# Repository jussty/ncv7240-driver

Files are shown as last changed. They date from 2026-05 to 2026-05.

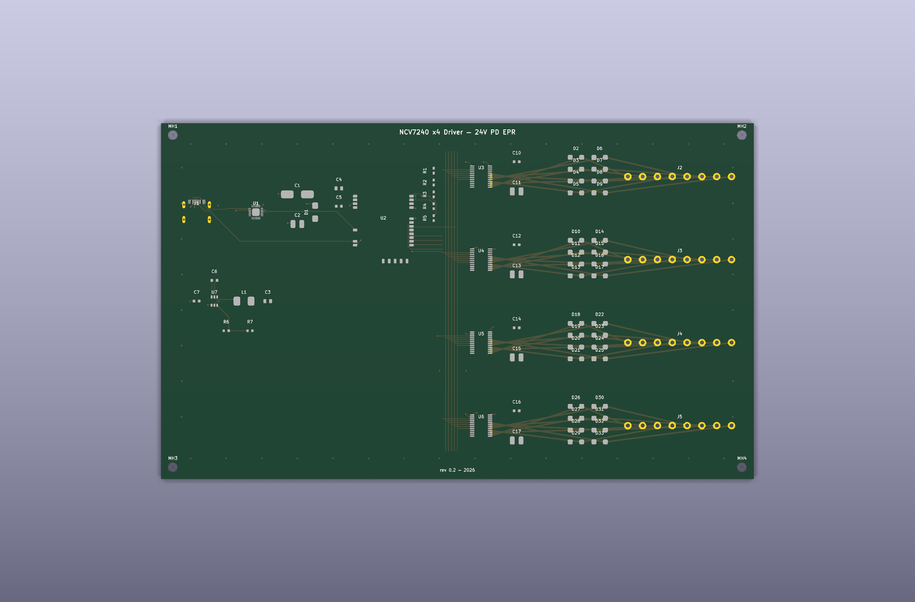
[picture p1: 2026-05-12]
board-top-routed.png

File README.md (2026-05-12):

# NCV7240 x4 — ESP32 + USB-C PD EPR (24 V) Driver Board

A KiCad 8 project for a compact controller board that:

- Negotiates **24 V** from a USB-C **PD 3.1 EPR** source via the **AP33772S** sink controller.
- Hosts an **ESP32-S3** MCU for Wi-Fi/BT control, configuration and host comms.
- Drives **32 low-side switched outputs** at 24 V using **4 × NCV7240** octal low-side drivers (SPI-controlled).

> Status: skeleton — project files, design rules, net classes and BOM are in place. The schematic (`ncv7240-driver.kicad_sch`) and PCB (`ncv7240-driver.kicad_pcb`) are intentionally empty placeholders ready to be populated in KiCad 8.

---

## 1. System architecture

```
       USB-C (PD 3.1 EPR, up to 28 V / 5 A)
           │
           ▼
   ┌────────────────┐   I²C   ┌──────────────────────┐
   │   AP33772S     │◀───────▶│   ESP32-S3-WROOM-1   │
   │  PD EPR sink   │  (CFG)  │  (Wi-Fi / BT / USB)  │
   └──────┬─────────┘         └───────┬──────────────┘
          │ VBUS_OUT = 24 V           │ SPI (CS x4, SCK, MOSI, MISO)
          │                           │ + RSTB, /FSO IRQ
          ▼                           ▼
   ┌──────────────┐   ┌──────────────┐   ┌──────────────┐   ┌──────────────┐
   │  NCV7240 #1  │   │  NCV7240 #2  │   │  NCV7240 #3  │   │  NCV7240 #4  │
   │ 8 ch low-side│   │ 8 ch low-side│   │ 8 ch low-side│   │ 8 ch low-side│
   └──────┬───────┘   └──────┬───────┘   └──────┬───────┘   └──────┬───────┘
          ▼                  ▼                  ▼                  ▼
       OUT1..8            OUT9..16          OUT17..24          OUT25..32
       (loads sink to GND; common rail = 24 V)
```

- The AP33772S handles all CC negotiation/PPS/EPR; the ESP32 just configures the
  request profile over I²C and reads VBUS / status telemetry.
- The 4 NCV7240s share SCK/MOSI/MISO/RSTB/SI on a single SPI bus; each has its
  own **/CSB** from the ESP32. Output enable is per-channel via SPI control word.

## 2. Bill of materials (core)

| Ref | Part | Pkg | Notes |
|---|---|---|---|
| U1 | AP33772S | QFN-24 | USB-C PD 3.1 EPR sink controller |
| U2 | ESP32-S3-WROOM-1-N8R8 | SMD module | 8 MB flash, 8 MB PSRAM |
| U3..U6 | NCV7240ADQR2G | SSOP-24 | Octal low-side driver, SPI |
| J1 | USB-C receptacle (EPR rated)  | TID/16-pin | 5 A continuous, EPR cable required >3 A  |
| D1 | TVS for VBUS (e.g. SMBJ33A) | SMB | 33 V standoff |
| L1 | 10 µH @ 3 A ferrite/inductor  | 1210 | VBUS LC filter (optional) |
| C_BULK | 100 µF / 50 V × 2 | electrolytic | VBUS bulk on 24 V rail |
| FB1..FB4  | Ferrite bead, 600 Ω @ 100 MHz | 0603 | Per-NCV7240 V_PWR decoupling |
| U7 | LDO/buck 24 V → 3.3 V (e.g. MP2451 or TPS62932) | SOT-23-6 | ≥500 mA for ESP32 peaks |
| U8 | (optional) 3.3 V LDO | SOT-23-5 | Clean rail for analog if needed |
| Q_GATE | P-MOSFET (e.g. DMP3098L) | SOT-23 | Reverse-polarity / VBUS gate (optional)  |
| R_CS | 1 % shunts | 0805 | If per-bank current sensing is desired |

Plus per-channel flyback diodes/TVS if driving inductive loads (the NCV7240
has internal active clamp, but external TVS to 24 V rail is recommended for
solenoids/relays).

## 3. Net classes / design rules

Defined in `ncv7240-driver.kicad_pro`:

| Net class | Track | Clearance | Vias | Used for |
|---|---|---|---|---|
| Default | 0.25  | 0.20 | 0.6 / 0.3 | logic, SPI, I²C |
| Power_24V | 0.80  | 0.40 | 0.9 / 0.4 | VBUS, 24 V plane feeds, OUTx pours |
| USB_PD | 0.40  | 0.25 | 0.7 / 0.3 | CC1/CC2, VBUS sense, D+/D- (90 Ω diff)|

## 4. Pin assignment (ESP32-S3 → NCVs / AP33772S)

| ESP32 pin | Net | Goes to |
|---|---|---|
| GPIO10 | SPI_CS1 | NCV7240 #1 /CSB |
| GPIO11 | SPI_CS2 | NCV7240 #2 /CSB |
| GPIO12 | SPI_CS3 | NCV7240 #3 /CSB |
| GPIO13 | SPI_CS4 | NCV7240 #4 /CSB |
| GPIO14 | SPI_SCK | all NCV7240 SCLK |
| GPIO15 | SPI_MOSI | all NCV7240 SI |
| GPIO16 | SPI_MISO | all NCV7240 SO (open-drain, ext. pull-up)|
| GPIO17 | NCV_RSTB | all NCV7240 /RSTB (active low, pull-up)  |
| GPIO18 | NCV_FSO | all NCV7240 /FSO fault flag (IRQ) |
| GPIO8 | I2C_SDA | AP33772S SDA (+ 4.7 kΩ pull-up to 3V3) |
| GPIO9 | I2C_SCL | AP33772S SCL (+ 4.7 kΩ pull-up to 3V3) |
| GPIO4 | PD_INT | AP33772S /INT |
| EN | reset btn | per ESP32 standard wiring |
| GPIO0 | boot btn | per ESP32 standard wiring |

> Avoid the strapping pins (GPIO0/3/45/46) and USB pins (19/20) for the
> dedicated nets above — already accounted for.

## 5. NCV7240 wiring notes

- Tie all `V_PWR` pins to the 24 V rail through individual ferrite beads
  + 100 nF + 10 µF local decoupling per IC.
- All `GND` pins tied to the solid 24 V-return ground pour.
- `SO` is open-drain; place one 10 kΩ pull-up to 3V3 on the shared MISO net.
- `/RSTB` shared and pulled up to 3V3 (10 kΩ); ESP32 drives low to reset all.
- `/FSO` shared open-drain fault flag → ESP32 IRQ, pulled up to 3V3.
- Daisy-chained SPI is **not** used here (independent /CSB per device is
  simpler and lets the ESP32 talk to any device individually at full clock).
- Each OUTx pad gets a generous copper pour and a screw terminal or 2.54 mm
  header per channel. For inductive loads, place a TVS/clamp diode from OUTx
  to the 24 V rail close to the load connector.

## 6. AP33772S notes

- Connect CC1/CC2 directly to the USB-C receptacle CC pins (no Rd needed —
  the AP33772S provides the sink termination).
- VBUS sense via internal divider; place 100 µF + 10 µF + 100 nF bulk on
  VBUS_OUT after the controller's NMOS pass switch.
- Pull `VPP` / `VDD` decoupling per datasheet (1 µF on VDD, 100 nF on VPP).
- The MCU configures the requested PDO (request 24 V/3 A EPR profile) via I²C
  at boot. Until configured the AP33772S falls back to its NVM defaults — flash
  the NVM with the desired default PDO request before deployment if you want
  the rail to come up without the ESP32.
- Add a SMBJ33A TVS across VBUS_OUT to GND.

## 7. Layout guidance

- 4-layer stack recommended: **Signal / GND / 24 V / Signal**.
- Keep the 24 V rail as a continuous pour on an inner layer; stitch with vias
  near each NCV7240 V_PWR pin.
- USB-C D+/D- routed as a 90 Ω differential pair, length-matched, away from
  the switching loads. (For PD-only operation D± are unused but route them
  anyway so the port can carry USB 2.0 data if desired.)
- Place the AP33772S close to the USB-C connector; keep the VBUS path short
  and wide (≥ 60 mil for 5 A).
- ESP32 antenna keep-out: leave ≥ 15 mm clearance and no copper under the
  antenna section of the module.
- Per-channel output traces: 0.8 mm minimum for 0.5 A loads, scale up for
  more. Add 2× thermal-relief pads at each NCV7240 exposed pad.

## 8. Loads — Bürkert Type 0127 valves (inductive)

Outputs drive **Bürkert Type 0127 rocker solenoid valves** (24 V DC,
**3 W ⇒ ≈125 mA per coil**). 32 channels × 125 mA = **4 A peak** on the
24 V rail — that's why we request a 24 V / 3-5 A EPR profile from the source.

Because the loads are inductive, every output has a **B260A-13-F** Schottky
(60 V / 2 A, SMA) freewheel diode:

  **Anode → OUTx, Cathode → +24V rail.**

When the NCV7240's low-side switch opens, the coil's collapsing field
drives OUTx above +24 V; the diode forward-biases at ≈0.7 V and recirculates
the coil current back into the rail, clamping OUTx to roughly `+24V + Vf`.
This is faster and dissipates less per-event than relying on the NCV7240's
internal active clamp (≈45 V).

> Place the freewheel diodes physically close to the screw terminal pads so
> the loop area between coil, diode and ground is minimised — important for
> EMI on a board switching 32 inductive loads.

## 9. Files

```
ncv7240-driver/
├── .gitignore
├── README.md
├── fp-lib-table  /  sym-lib-table
├── ncv7240-driver.kicad_pro   # KiCad 8 project, design rules + net classes
├── ncv7240-driver.kicad_sch   # generated by tools/gen_sch.py
├── ncv7240-driver.kicad_pcb   # generated by tools/gen_pcb.py
├── datasheets/                # versioned vendor PDFs
│   ├── ncv7240.pdf            (onsemi)
│   ├── ap33772s.pdf           (Diodes Inc)
│   ├── esp32-s3-wroom-1.pdf   (Espressif)
│   ├── b260a.pdf              (Diodes Inc — flyback Schottky)
│   └── burkert-0127.pdf       (Bürkert — load)
└── tools/
    ├── gen_sch.py             # deterministic schematic generator
    └── gen_pcb.py             # deterministic PCB skeleton generator
```

Regenerate after editing the generators:

```sh
python3 tools/gen_sch.py > ncv7240-driver.kicad_sch
python3 tools/gen_pcb.py > ncv7240-driver.kicad_pcb
```

Open `ncv7240-driver.kicad_pro` in **KiCad 8.0 or newer**. In Pcbnew:

1. **Tools → Update PCB from Schematic** to import all 30+ footprints
   from the standard KiCad libraries (you'll need them installed locally —
   they ship with KiCad).
2. Components arrive at the origin; drag them into the marked floorplan
   zones (visible on `User.Comments`).
3. Route, fill the GND and +24V zones, run DRC, export Gerbers to `gerbers/`.

## 10. Board floorplan (160 × 100 mm, 4-layer)

```
+----------------------------------------------------------------------+
|              NCV7240 x4 Driver — 24V PD EPR    (silkscreen header)   |
|                                                                      |
|  +--------+ +-------------+ +-------------+ +--------+ +----------+  |
|  |USB-C PD| | Buck 24V→3V3| |             | |  4×    | |  Screw   |  |
|  |  J1 U1 | |  U7 L1 C3   | |  ESP32-S3   | | NCV    | |  termi-  |  |
|  | C1/C2  | +-------------+ |   U2        | | 7240   | |  nals    |  |
|  |  D1    |                 | C4 C5       | | U3-U6  | | J2..J5   |  |
|  |        | (44-90, 6-36)   | R1..R5      | |        | |          |  |
|  |        |                 |             | |        | |          |  |
|  |        | +-------------+ |             | +--------+ +----------+  |
|  |        | |             | |             | | Flyback diode field   |  |
|  |        | |    ESP32    | |             | | D2..D33  B260A-SMA    |  |
|  | (4-44, | |  (44-90,    | | (44-90,     | | (90-156,              |  |
|  |  6-60) | |   36-96)    | |  36-96)     | |  60-96)               |  |
|  +--------+ +-------------+ +-------------+ +--------+ +----------+  |
|                                                                      |
+----------------------------------------------------------------------+
```

4-layer stackup: **F.Cu / GND / +24V / B.Cu** (1.6 mm FR4, ENIG finish).

## 9. License

Hardware: CERN-OHL-S v2 (recommended) — adjust to your needs.

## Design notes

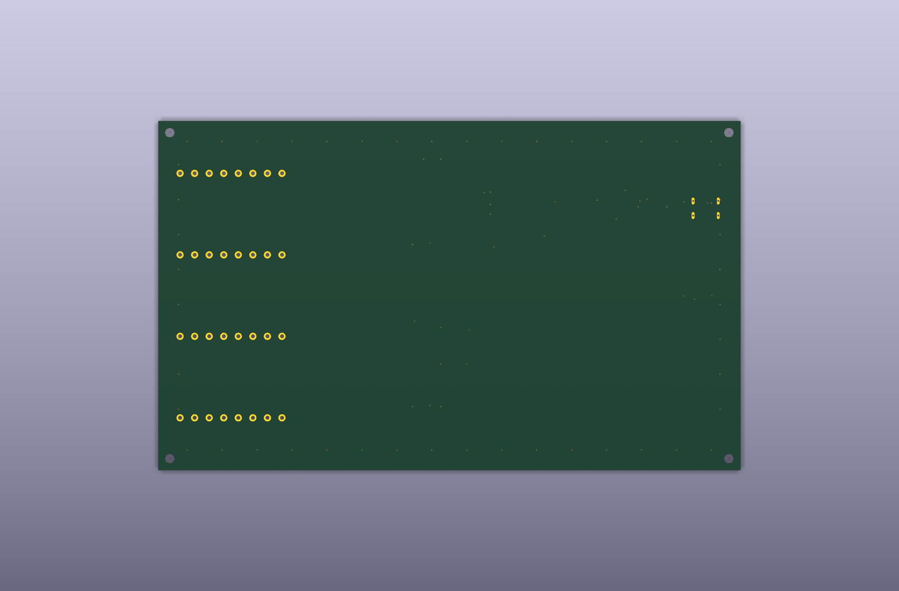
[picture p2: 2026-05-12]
board-bottom-routed.png

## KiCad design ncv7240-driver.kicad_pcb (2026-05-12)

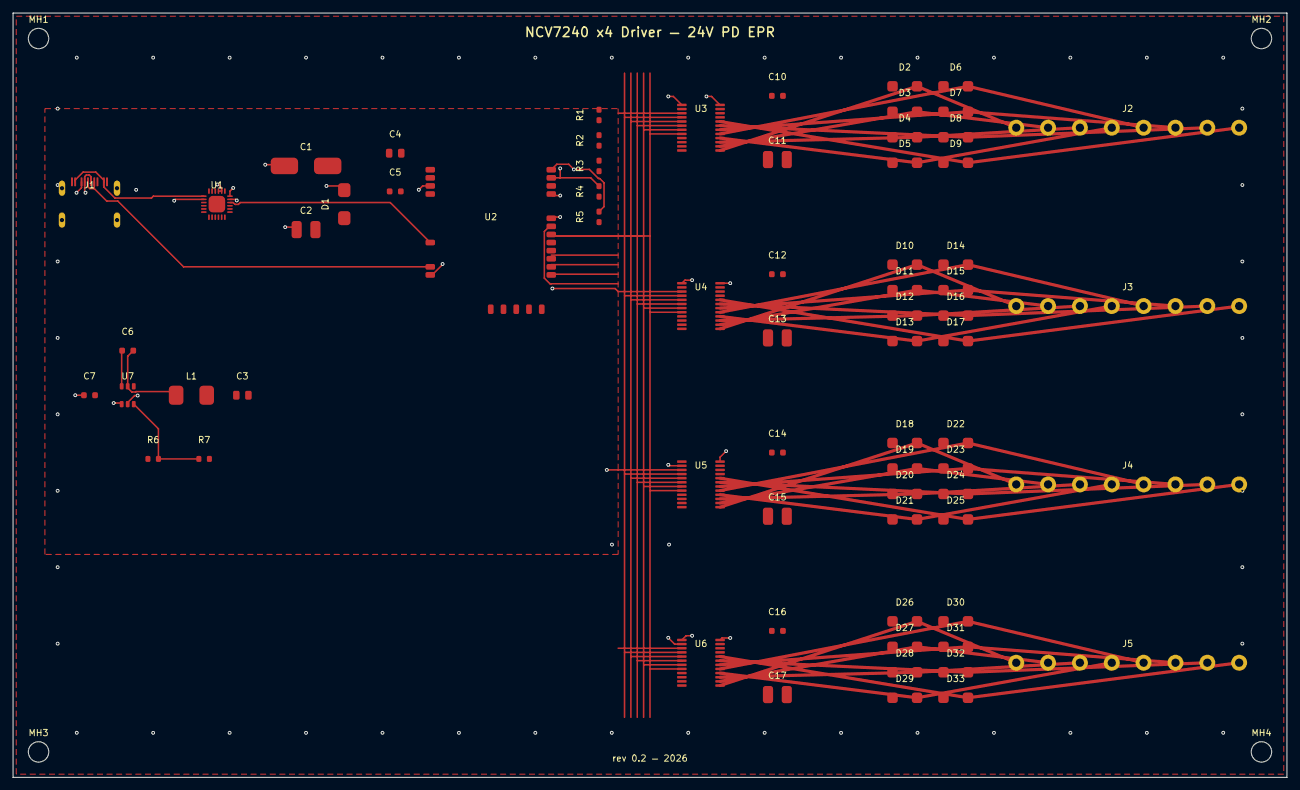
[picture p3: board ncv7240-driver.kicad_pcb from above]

Board: 4 copper layers, 200.0 x 120.0 mm, 72 parts (0 on the bottom side), 56 nets.

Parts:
C1: 100uF/50V; CP_Elec_10x10.5
C2, C11, C13, C15, C17: 10uF/50V; C_1210_3225Metric
C3: 22uF; C_0805_2012Metric
C4: 10uF; C_0805_2012Metric
C5, C6, C7, C10, C12, C14, C16: 100nF; C_0603_1608Metric
D1: SMBJ33A; D_SMB
D2, D3, D4, D5, D6, D7, D8, D9, D10, D11, D12, D13, D14, D15, D16, D17, D18, D19, D20, D21, D22, D23, D24, D25, D26, D27, D28, D29, D30, D31, D32, D33: B260A; D_SMA
J1: USB-C; USB_C_Receptacle_HRO_TYPE-C-31-M-12
J2: OUT1-8; TerminalBlock_Phoenix_MKDS-1,5-8_1x08_P5.00mm_Horizontal
J3: OUT9-16; TerminalBlock_Phoenix_MKDS-1,5-8_1x08_P5.00mm_Horizontal
J4: OUT17-24; TerminalBlock_Phoenix_MKDS-1,5-8_1x08_P5.00mm_Horizontal
J5: OUT25-32; TerminalBlock_Phoenix_MKDS-1,5-8_1x08_P5.00mm_Horizontal
L1: 4.7uH/2A; L_Bourns-SRN6045TA
MH1, MH2, MH3, MH4: M3; MountingHole_3.2mm_M3
R1, R2, R3: 10k; R_0603_1608Metric
R4, R5: 4.7k; R_0603_1608Metric
R6: 100k; R_0603_1608Metric
R7: 20k; R_0603_1608Metric
U1: AP33772S; QFN-24-1EP_4x4mm_P0.5mm_EP2.6x2.6mm
U2: ESP32-S3-WROOM-1
U3, U4, U5, U6: NCV7240; SSOP-24_5.3x8.2mm_P0.65mm
U7: TPS62932; SOT-23-6

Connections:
+3V3: C3.1, C4.1, C5.1, L1.2, R1.1, R2.1, R3.1, R4.1, R5.1, R6.1, U1.4, U2.2, U3.2, U4.2, U5.2, U6.2
+24V: C1.1, C2.1, C7.1, C10.1, C11.1, C12.1, C13.1, C14.1, C15.1, C16.1, C17.1, D1.2, D2.1, D3.1, D4.1, D5.1, D6.1, D7.1, D8.1, D9.1, D10.1, D11.1, D12.1, D13.1, D14.1, D15.1, D16.1, D17.1, D18.1, D19.1, D20.1, D21.1, D22.1, D23.1, D24.1, D25.1, D26.1, D27.1, D28.1, D29.1, D30.1, D31.1, D32.1, D33.1, U1.20, U1.21, U3.1, U3.24, U4.1, U4.24, U5.1, U5.24, U6.1, U6.24, U7.6
BST: C6.1, U7.1
CC1: J1.4, U1.2
CC2: J1.9, U1.3
EN_3V3: U2.3, U7.5
FB: R6.2, R7.1, U7.4
GND: C1.2, C2.2, C3.2, C4.2, C5.2, C7.2, C10.2, C11.2, C12.2, C13.2, C14.2, C15.2, C16.2, C17.2, D1.1, J1.1, J1.12, J1.SH, R7.2, U1.5, U1.6, U1.7, U1.8, U1.9, U1.10, U1.11, U1.12, U1.13, U1.14, U1.15, U1.22, U1.23, U1.24, U1.25, U2.1, U2.27, U2.37, U2.38, U2.39, U2.40, U2.41, U3.9, U3.10, U3.11, U3.12, U3.21, U3.22, U3.23, U4.9, U4.10, U4.11, U4.12, U4.21, U4.22, U4.23, U5.9, U5.10, U5.11, U5.12, U5.21, U5.22, U5.23, U6.9, U6.10, U6.11, U6.12, U6.21, U6.22, U6.23, U7.3
I2C_SCL: R5.2, U1.17, U2.17
I2C_SDA: R4.2, U1.18, U2.18
NCV_FSOB: R3.2, U2.30, U3.8, U4.8, U5.8, U6.8
NCV_RSTB: R2.2, U2.29, U3.7, U4.7, U5.7, U6.7
OUT1: D2.2, J2.1, U3.13
OUT2: D3.2, J2.2, U3.14
OUT3: D4.2, J2.3, U3.15
OUT4: D5.2, J2.4, U3.16
OUT5: D6.2, J2.5, U3.17
OUT6: D7.2, J2.6, U3.18
OUT7: D8.2, J2.7, U3.19
OUT8: D9.2, J2.8, U3.20
OUT9: D10.2, J3.1, U4.13
OUT10: D11.2, J3.2, U4.14
OUT11: D12.2, J3.3, U4.15
OUT12: D13.2, J3.4, U4.16
OUT13: D14.2, J3.5, U4.17
OUT14: D15.2, J3.6, U4.18
OUT15: D16.2, J3.7, U4.19
OUT16: D17.2, J3.8, U4.20
OUT17: D18.2, J4.1, U5.13
OUT18: D19.2, J4.2, U5.14
OUT19: D20.2, J4.3, U5.15
OUT20: D21.2, J4.4, U5.16
OUT21: D22.2, J4.5, U5.17
OUT22: D23.2, J4.6, U5.18
OUT23: D24.2, J4.7, U5.19
OUT24: D25.2, J4.8, U5.20
OUT25: D26.2, J5.1, U6.13
OUT26: D27.2, J5.2, U6.14
OUT27: D28.2, J5.3, U6.15
OUT28: D29.2, J5.4, U6.16
OUT29: D30.2, J5.5, U6.17
OUT30: D31.2, J5.6, U6.18
OUT31: D32.2, J5.7, U6.19
OUT32: D33.2, J5.8, U6.20
PD_INT: U1.16, U2.10
SPI_CS1: U2.19, U3.3
SPI_CS2: U2.20, U4.3
SPI_CS3: U2.23, U5.3
SPI_CS4: U2.24, U6.3
SPI_MISO: R1.2, U2.28, U3.6, U4.6, U5.6, U6.6
SPI_MOSI: U2.26, U3.5, U4.5, U5.5, U6.5
SPI_SCK: U2.25, U3.4, U4.4, U5.4, U6.4
SW: C6.2, L1.1, U7.2
USB_D+: J1.5, J1.7, U2.14
USB_D-: J1.6, J1.8, U2.13
VBUS: J1.2, J1.11, U1.1

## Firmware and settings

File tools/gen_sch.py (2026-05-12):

#!/usr/bin/env python3
"""
Generate ncv7240-driver.kicad_sch — a KiCad 8 schematic with all symbols
embedded inline so it renders correctly in kicanvas.org without external libs.

The schematic is block-diagram style: each IC is a rectangular symbol with
its used pins exposed; interconnects are expressed as KiCad global labels so
the connectivity is unambiguous without exhaustive wire routing.

Run from the repo root:
    python3 tools/gen_sch.py > ncv7240-driver.kicad_sch
"""

import uuid
import sys

# ---------- helpers ---------------------------------------------------------

# Deterministic UUIDs so re-runs produce byte-identical output (nice for git).
_uuid_counter = 0
def u():
    global _uuid_counter
    _uuid_counter += 1
    return f"00000000-0000-0000-0000-{_uuid_counter:012x}"

def eff(size=1.27, justify=None, hide=False):
    parts = [f"(font (size {size} {size}))"]
    if justify:
        parts.append(f"(justify {justify})")
    if hide:
        parts.append("hide")
    return "(effects " + " ".join(parts) + ")"

# ---------- symbol library --------------------------------------------------
# Each entry: ( "Lib:Name", [pins], width, height, ref_prefix )
# pin: (number, name, side, y_offset, etype)   side in L/R/T/B
# etype: input/output/bidirectional/power_in/passive/open_collector/...

def sym(name, ref, value, pins, w, h, power=False, fp=""):
    """Emit a (symbol ...) library entry."""
    out = []
    short = name.split(":", 1)[-1]
    out.append(f'(symbol "{name}"')
    out.append('  (pin_names (offset 0.508))')
    out.append('  (exclude_from_sim no) (in_bom yes) (on_board yes)')
    if power:
        out.append('  (power)')
    out.append(f'  (property "Reference" "{ref}" (at 0 {h/2+2.54:.2f} 0) {eff()})')
    out.append(f'  (property "Value" "{value}" (at 0 {-h/2-2.54:.2f} 0) {eff()})')
    out.append(f'  (property "Footprint" "{fp}" (at 0 0 0) {eff(hide=True)})')
    out.append(f'  (property "Datasheet" "" (at 0 0 0) {eff(hide=True)})')
    out.append(f'  (symbol "{short}_0_1"')
    if not power:
        out.append(f'    (rectangle (start {-w/2:.2f} {h/2:.2f}) (end {w/2:.2f} {-h/2:.2f})')
        out.append('      (stroke (width 0.254) (type default))')
        out.append('      (fill (type background))')
        out.append('    )')
    out.append('  )')
    out.append(f'  (symbol "{short}_1_1"')
    for (num, pname, side, yoff, etype) in pins:
        if side == 'L':
            x, y, rot = -w/2 - 2.54, yoff, 0
        elif side == 'R':
            x, y, rot = w/2 + 2.54, yoff, 180
        elif side == 'T':
            x, y, rot = yoff, h/2 + 2.54, 270
        else:  # B
            x, y, rot = yoff, -h/2 - 2.54, 90
        out.append(f'    (pin {etype} line (at {x:.2f} {y:.2f} {rot}) (length 2.54)')
        out.append(f'      (name "{pname}" {eff()})')
        out.append(f'      (number "{num}" {eff()})')
        out.append('    )')
    out.append('  )')
    out.append(')')
    return "\n".join(out)

# ---- Power symbols (special: invisible body, single pin pointing up) -------
def pwr_sym(name, label):
    short = name.split(":", 1)[-1]
    return f'''(symbol "{name}"
  (power) (pin_names (offset 0)) (in_bom yes) (on_board yes)
  (property "Reference" "#PWR" (at 0 -3.81 0) {eff(hide=True)})
  (property "Value" "{label}" (at 0 3.556 0) {eff()})
  (property "Footprint" "" (at 0 0 0) {eff(hide=True)})
  (property "Datasheet" "" (at 0 0 0) {eff(hide=True)})
  (symbol "{short}_0_1"
    (polyline (pts (xy -1.016 -0.508) (xy 0 0.762) (xy 1.016 -0.508) (xy -1.016 -0.508))
      (stroke (width 0) (type default)) (fill (type none))
    )
  )
  (symbol "{short}_1_1"
    (pin power_in line (at 0 0 90) (length 0)
      (name "{label}" {eff(hide=True)})
      (number "1" {eff(hide=True)})
    )
  )
)'''

# ---- Symbol definitions used in this schematic -----------------------------

LIB = []

# Power flags
LIB.append(pwr_sym("power:+24V",  "+24V"))
LIB.append(pwr_sym("power:+3V3",  "+3V3"))
LIB.append(pwr_sym("power:VBUS",  "VBUS"))
LIB.append(pwr_sym("power:GND",   "GND"))

# Resistor
LIB.append('''(symbol "Device:R"
  (pin_names (offset 0) hide) (exclude_from_sim no) (in_bom yes) (on_board yes)
  (property "Reference" "R" (at 2.032 0 90) ''' + eff() + ''')
  (property "Value" "R" (at 0 0 90) ''' + eff() + ''')
  (property "Footprint" "" (at 0 0 0) ''' + eff(hide=True) + ''')
  (property "Datasheet" "" (at 0 0 0) ''' + eff(hide=True) + ''')
  (symbol "R_0_1"
    (rectangle (start -1.016 -2.54) (end 1.016 2.54)
      (stroke (width 0.254) (type default)) (fill (type none))
    )
  )
  (symbol "R_1_1"
    (pin passive line (at 0  3.81 270) (length 1.27) (name "~" ''' + eff() + ''') (number "1" ''' + eff() + '''))
    (pin passive line (at 0 -3.81 90)  (length 1.27) (name "~" ''' + eff() + ''') (number "2" ''' + eff() + '''))
  )
)''')

# Capacitor
LIB.append('''(symbol "Device:C"
  (pin_names (offset 0.254) hide) (exclude_from_sim no) (in_bom yes) (on_board yes)
  (property "Reference" "C" (at 2.032 0 90) ''' + eff() + ''')
  (property "Value" "C" (at 0 -3.81 0) ''' + eff() + ''')
  (property "Footprint" "" (at 0 0 0) ''' + eff(hide=True) + ''')
  (property "Datasheet" "" (at 0 0 0) ''' + eff(hide=True) + ''')
  (symbol "C_0_1"
    (polyline (pts (xy -2.032 -0.762) (xy 2.032 -0.762)) (stroke (width 0.508) (type default)) (fill (type none)))
    (polyline (pts (xy -2.032  0.762) (xy 2.032  0.762)) (stroke (width 0.508) (type default)) (fill (type none)))
  )
  (symbol "C_1_1"
    (pin passive line (at 0  3.81 270) (length 2.794) (name "~" ''' + eff() + ''') (number "1" ''' + eff() + '''))
    (pin passive line (at 0 -3.81 90)  (length 2.794) (name "~" ''' + eff() + ''') (number "2" ''' + eff() + '''))
  )
)''')

# Inductor
LIB.append('''(symbol "Device:L"
  (pin_names (offset 1.016) hide) (exclude_from_sim no) (in_bom yes) (on_board yes)
  (property "Reference" "L" (at -1.27 0 90) ''' + eff() + ''')
  (property "Value" "L" (at 1.905 0 90) ''' + eff() + ''')
  (property "Footprint" "" (at 0 0 0) ''' + eff(hide=True) + ''')
  (property "Datasheet" "" (at 0 0 0) ''' + eff(hide=True) + ''')
  (symbol "L_0_1"
    (arc (start 0 -2.54) (mid 0.7239 -1.905) (end 0 -1.27) (stroke (width 0) (type default)) (fill (type none)))
    (arc (start 0 -1.27) (mid 0.7239 -0.635) (end 0  0.00) (stroke (width 0) (type default)) (fill (type none)))
    (arc (start 0  0.00) (mid 0.7239  0.635) (end 0  1.27) (stroke (width 0) (type default)) (fill (type none)))
    (arc (start 0  1.27) (mid 0.7239  1.905) (end 0  2.54) (stroke (width 0) (type default)) (fill (type none)))
  )
  (symbol "L_1_1"
    (pin passive line (at 0  3.81 270) (length 1.27) (name "~" ''' + eff() + ''') (number "1" ''' + eff() + '''))
    (pin passive line (at 0 -3.81 90)  (length 1.27) (name "~" ''' + eff() + ''') (number "2" ''' + eff() + '''))
  )
)''')
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

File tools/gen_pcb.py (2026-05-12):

#!/usr/bin/env python3
"""
Generate ncv7240-driver.kicad_pcb — fully placed 4-layer PCB.

Board:  200 × 120 mm, 4-layer (F.Cu / GND / +24V / B.Cu), 1.6 mm FR4 ENIG.

What this generator does:
  - Emits a valid KiCad 8 board file.
  - Inlines minimal but valid footprint geometry (pads + courtyard) for every
    component so kicanvas.org can render it directly from GitHub.
  - Pre-places every component into the floorplan from the schematic.
  - Assigns nets to all pads (matches schematic net list).
  - Pours GND on In1.Cu + B.Cu and +24V on In2.Cu.
  - Drops power vias from each IC's V+/GND pad down to the relevant plane.
  - Routes the SPI/I²C signal bus on F.Cu.
  - Leaves the 32 OUTx flyback-to-screw-terminal traces for KiCad's router
    to finish (geometry is repetitive and trivial to autoroute).

Run from repo root:
    python3 tools/gen_pcb.py > ncv7240-driver.kicad_pcb
"""

import sys

# ---------- deterministic UUIDs --------------------------------------------
_uc = 0
def u():
    global _uc; _uc += 1
    return f"00000000-1111-0000-0000-{_uc:012x}"

# ---------- board dimensions ----------------------------------------------
W, H = 200.0, 120.0           # board size mm
MH_INSET = 4.0
MH_DRILL = 3.2
MH_PAD   = 6.0

# ---------- nets list (must match schematic) ------------------------------
NETS = [
    "", "GND", "+24V", "+3V3", "VBUS",
    "CC1", "CC2",
    "I2C_SDA", "I2C_SCL", "PD_INT", "PD_VOUT_EN",
    "SPI_SCK", "SPI_MOSI", "SPI_MISO",
    "SPI_CS1", "SPI_CS2", "SPI_CS3", "SPI_CS4",
    "NCV_RSTB", "NCV_FSOB",
    "RST_BTN", "BOOT_BTN", "EN_3V3",
    "USB_D+", "USB_D-",
    "BST", "SW", "FB",  # buck local nets
    "SBU1", "SBU2",     # unused but declared
] + [f"OUT{k}" for k in range(1, 33)]
NET = {n: i for i, n in enumerate(NETS)}

# ---------- emit helpers ---------------------------------------------------
OUT = []
def emit(s): OUT.append(s)

def pad_smd(num, x, y, w, h, net):
    """SMD pad on F.Cu (rectangular)."""
    return (f'    (pad "{num}" smd roundrect (at {x:.3f} {y:.3f}) (size {w:.3f} {h:.3f})'
            f' (layers "F.Cu" "F.Paste" "F.Mask") (roundrect_rratio 0.25)'
            f' (net {NET[net]} "{net}") (uuid "{u()}"))')

def pad_th(num, x, y, dia, drill, net, oval=False, w=None, h=None):
    """Through-hole pad, all copper layers."""
    if oval:
        return (f'    (pad "{num}" thru_hole oval (at {x:.3f} {y:.3f}) (size {w} {h})'
                f' (drill {drill}) (layers "*.Cu" "*.Mask")'
                f' (net {NET[net]} "{net}") (uuid "{u()}"))')
    return (f'    (pad "{num}" thru_hole circle (at {x:.3f} {y:.3f}) (size {dia} {dia})'
            f' (drill {drill}) (layers "*.Cu" "*.Mask")'
            f' (net {NET[net]} "{net}") (uuid "{u()}"))')

def pad_np(x, y, dia):
    """Non-plated through hole (mounting)."""
    return (f'    (pad "" np_thru_hole circle (at {x} {y}) (size {dia} {dia})'
            f' (drill {dia}) (layers "F&B.Cu" "*.Mask") (uuid "{u()}"))')

def fp_open(lib, ref, value, x, y, rot, layer="F.Cu", attrs="smd"):
    return [
        f'  (footprint "{lib}" (layer "{layer}") (uuid "{u()}") (at {x} {y} {rot})',
        f'    (attr {attrs})',
        f'    (property "Reference" "{ref}" (at 0 -3 {rot}) (layer "F.SilkS")',
        f'      (uuid "{u()}") (effects (font (size 1 1) (thickness 0.15))))',
        f'    (property "Value" "{value}" (at 0 3 {rot}) (layer "F.Fab")',
        f'      (uuid "{u()}") (effects (font (size 0.8 0.8) (thickness 0.12))))',
    ]

def fp_close():
    return ['  )']

def via(x, y, net, drill=0.3, dia=0.6):
    emit(f'  (via (at {x:.3f} {y:.3f}) (size {dia}) (drill {drill})'
         f' (layers "F.Cu" "B.Cu") (net {NET[net]}) (uuid "{u()}"))')

def track(x1, y1, x2, y2, net, layer="F.Cu", width=0.25):
    emit(f'  (segment (start {x1:.3f} {y1:.3f}) (end {x2:.3f} {y2:.3f})'
         f' (width {width}) (layer "{layer}") (net {NET[net]}) (uuid "{u()}"))')

# ---------- footprint factories (placed at component's local origin) -------

def _two_pad(lib, ref, value, x, y, rot, px, pw, ph, n1, n2):
    """Generic 2-pad SMD footprint. Pads at LOCAL (±px, 0); KiCad rotates."""
    out = fp_open(lib, ref, value, x, y, rot)
    out.append(pad_smd("1", -px, 0, pw, ph, n1))
    out.append(pad_smd("2", +px, 0, pw, ph, n2))
    out.extend(fp_close()); emit("\n".join(out))

def place_r0603(ref, value, x, y, rot, n1, n2):
    _two_pad("Resistor_SMD:R_0603_1608Metric", ref, value, x, y, rot, 0.825, 0.8, 0.95, n1, n2)

def place_c0603(ref, value, x, y, rot, n1, n2):
    _two_pad("Capacitor_SMD:C_0603_1608Metric", ref, value, x, y, rot, 0.875, 0.9, 0.95, n1, n2)

def place_c0805(ref, value, x, y, rot, n1, n2):
    _two_pad("Capacitor_SMD:C_0805_2012Metric", ref, value, x, y, rot, 0.95, 1.025, 1.4, n1, n2)

def place_c1210(ref, value, x, y, rot, n1, n2):
    _two_pad("Capacitor_SMD:C_1210_3225Metric", ref, value, x, y, rot, 1.475, 1.6, 2.7, n1, n2)

def place_cp_elec(ref, value, x, y, rot, n_pos, n_neg):
    _two_pad("Capacitor_SMD:CP_Elec_10x10.5", ref, value, x, y, rot, 3.4, 4.3, 2.6, n_pos, n_neg)

def place_inductor(ref, value, x, y, rot, n1, n2):
    _two_pad("Inductor_SMD:L_Bourns-SRN6045TA", ref, value, x, y, rot, 2.4, 2.3, 3.0, n1, n2)

def place_dsma(ref, value, x, y, rot, n_k, n_a):
    _two_pad("Diode_SMD:D_SMA", ref, value, x, y, rot, 1.925, 1.65, 1.65, n_k, n_a)

def place_dsmb(ref, value, x, y, rot, n_k, n_a):
    _two_pad("Diode_SMD:D_SMB", ref, value, x, y, rot, 2.2, 1.95, 2.2, n_k, n_a)

def place_sot23_6(ref, value, x, y, rot, pin_nets):
    """SOT-23-6 — pads local; footprint rotation handles orientation."""
    out = fp_open("Package_TO_SOT_SMD:SOT-23-6", ref, value, x, y, rot)
    pos = [(-0.95,-1.4),(0,-1.4),(0.95,-1.4),(0.95,1.4),(0,1.4),(-0.95,1.4)]
    for i,(dx,dy) in enumerate(pos):
        out.append(pad_smd(str(i+1), dx, dy, 0.6, 1.0, pin_nets[i]))
    out.extend(fp_close()); emit("\n".join(out))

def place_qfn24_4mm(ref, value, x, y, rot, pin_nets, ep_net="GND"):
    """QFN-24 4×4 mm P0.5; pads in LOCAL coords (no pre-rotation)."""
    out = fp_open("Package_DFN_QFN:QFN-24-1EP_4x4mm_P0.5mm_EP2.6x2.6mm",
                  ref, value, x, y, rot)
    P = 0.5
    side_offset = 2.05
    pin = 1
    for k in range(6):  # left (top to bottom)
        out.append(pad_smd(str(pin), -side_offset, -1.25 + k*P, 0.85, 0.25, pin_nets[pin-1]))
        pin += 1
    for k in range(6):  # bottom
        out.append(pad_smd(str(pin), -1.25 + k*P, side_offset, 0.25, 0.85, pin_nets[pin-1]))
        pin += 1
    for k in range(6):  # right (bottom to top)
        out.append(pad_smd(str(pin), side_offset, 1.25 - k*P, 0.85, 0.25, pin_nets[pin-1]))
        pin += 1
    for k in range(6):  # top (right to left)
        out.append(pad_smd(str(pin), 1.25 - k*P, -side_offset, 0.25, 0.85, pin_nets[pin-1]))
        pin += 1
    out.append(pad_smd("25", 0, 0, 2.6, 2.6, ep_net))  # exposed pad
    out.extend(fp_close()); emit("\n".join(out))
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

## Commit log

2026-05-11 Initial KiCad project: 4x NCV7240 + ESP32-S3 + AP33772S PD EPR 24V
    [ncv7240-driver.kicad_pcb, ncv7240-driver.kicad_sch]
2026-05-11 Draw block-diagram schematic with all symbols embedded for kicanvas
    - Python generator at tools/gen_sch.py produces ncv7240-driver.kicad_sch
    - All symbol definitions embedded inline (kicanvas has no external libs)
    - Components: USB-C, AP33772S, ESP32-S3-WROOM-1, 4x NCV7240, buck reg,
    bulk/decoupling caps, TVS, pull-ups, 8-pin output screw terminals
    - Connectivity via KiCad global labels (SPI bus, I2C, power rails, OUT1..32)
    - A2 sheet, deterministic UUIDs for clean diffs
    [ncv7240-driver.kicad_sch]
2026-05-12 Add 32 flyback diodes, real footprints, and parts datasheets
    - 32× B260A-13-F Schottky (60V / 2A SMA) freewheel diodes — one per
    output, anode→OUTx, cathode→+24V, for Bürkert Type 0127 valve coils
    (3 W @ 24 V ≈ 125 mA, inductive)
    - Footprints assigned for all parts:
    - NCV7240 SSOP-24 P0.65
    - AP33772S QFN-24 4x4 EP2.6
    - ESP32-S3-WROOM-1 (fixed from S2 typo)
    - USB-C HRO TYPE-C-31-M-12
    - Buck SOT-23-6
    - L1 Bourns SRN6045 4.7uH
    - Bulk caps CP_Elec_10x10.5 / C_1210
    - Decoupling C_0603 / C_0805
    - Resistors R_0603
    - TVS SMB
    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
    [ncv7240-driver.kicad_sch]
2026-05-12 Start PCB layout: 4-layer 160x100mm with floorplan and pours
    - tools/gen_pcb.py — deterministic PCB skeleton generator
    - 160 × 100 mm rectangular board outline on Edge.Cuts
    - 4-layer stackup: F.Cu / GND (In1) / +24V (In2) / B.Cu, 1.6 mm FR4 ENIG
    - 4× M3 mounting holes inset 4 mm from corners
    - 57 nets pre-declared (matches schematic: GND/+24V/+3V3/VBUS/CC/I2C/
    SPI/PD/USB/RST_BTN/BOOT_BTN + OUT1..OUT32)
    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
    [ncv7240-driver.kicad_pcb]
2026-05-12 Pre-place all 72 footprints into floorplan with net assignments
    200×120 mm 4-layer board, all components placed with embedded pad
    geometry so kicanvas can render the board directly. After opening in
    KiCad, 'Tools → Update PCB from Schematic' will refresh footprints
    to the full library geometry while preserving placement and nets.
    Placement (left → right):
    - USB-C J1 + AP33772S U1 + bulk caps C1/C2 + TVS D1
    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
    [ncv7240-driver.kicad_pcb]
2026-05-12 Route OUTx output paths and SPI/control bus
    - 32× output traces routed on F.Cu (0.5 mm width):
    NCV pin → flyback diode anode → screw terminal pin
    - Shared SPI/control bus on F.Cu (0.25 mm) in the gap between
    ESP32 and the NCV stack:
    SPI_SCK x=96
    SPI_MOSI x=97
    SPI_MISO x=98
    NCV_RSTB x=99
    NCV_FSOB x=100
    Vertical bus tracks span all 4 NCV ICs; horizontal stubs fan
    out to each NCV's left-side pin (4,5,6,7,8).
    - Per-NCV /CSB stubs (CS1..CS4 independent)
    - ESP32 → bus connector stubs (rough; KiCad can tidy)
    - Moved screw terminals from x=180 to x=175 for 3.5 mm clearance
    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
    [ncv7240-driver.kicad_pcb]
2026-05-12 pcb: add F.Cu GND zone, populate fp-lib-table, render board
    - Add low-priority F.Cu GND copper pour so perimeter stitching vias
    have something to anchor to on the top side.
    - Populate fp-lib-table with standard KiCad footprint libraries
    (Resistor_SMD, Capacitor_SMD, Diode_SMD, Package_SO, Package_DFN_QFN,
    RF_Module, Connector_USB, TerminalBlock_Phoenix, MountingHole, etc.)
    so KiCad GUI can resolve real library footprints when the user runs
    "Update PCB from Schematic".
    - Commit top/bottom render PNGs for quick review.
    - Ignore *.rpt files (DRC outputs).
    DRC state: 400 violations remain (219 unconnected nets needing routing,
    150 solder-mask bridges from placeholder OUTx tracks, 66 l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
    [ncv7240-driver.kicad_pcb]
2026-05-12 pcb: freerouting headless round-trip (partial)
    Set up a headless DSN→freerouting→SES round-trip:
    - DSN export via pcbnew Python bindings (ExportSpecctraDSN)
    - freerouting v2.2.3 run with --gui-disabled, 30 router passes,
    5 optimizer passes, 10-minute job timeout
    - SES import via pcbnew.ImportSpecctraSES
    Result: partial autoroute. 137 net segments at start, 98 still
    unrouted at timeout. DRC: 412 violations (196 unconnected items,
    150 solder-mask bridges, 67 tracks crossing, 62 dangling vias,
    plus the 66 lib_footprint_mismatch that will clear once the user
    runs Update PCB from Schematic in the GUI).
    Why incomplete: KiCad placement was done by gen_pcb.py using
    placeholder pad geometries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
    [ncv7240-driver.dsn, ncv7240-driver.kicad_pcb]
2026-05-12 sch: strip library prefix from child unit symbol names
    KiCad 10's parser rejects names like "power:+24V_0_1" with
    "Invalid symbol unit name prefix power:+24V_0_1". Inside a
    lib_symbols entry, the parent symbol carries the library prefix
    ("power:+24V") but the child unit symbols must use only the
    short form ("+24V_0_1", "+24V_1_1").
    Fixes the make_sym() and pwr_sym() helpers in gen_sch.py to
    split on ':' and use only the suffix for child names. The R/C/L/D
    inline templates were already correct (no prefix on children).
    [ncv7240-driver.kicad_sch]
